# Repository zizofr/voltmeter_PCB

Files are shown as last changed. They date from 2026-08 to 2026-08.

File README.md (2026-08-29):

# ⚡ Digital Voltmeter (Custom PCB & Hardware Design)

A compact digital voltmeter designed around a custom Printed Circuit Board (PCB) created in KiCad. This repository contains the complete hardware design files, schematics, Gerber manufacturing outputs, and board renders prior to final firmware integration.

---

## 🖼️ Hardware & PCB Gallery

### Board Renders & Views
| Top View | Bottom View |
| :---: | :---: |
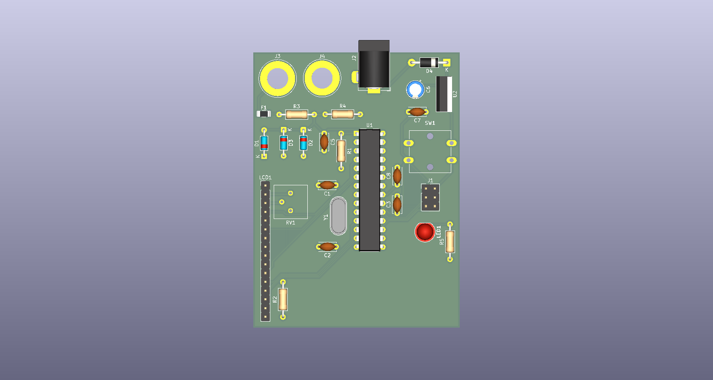
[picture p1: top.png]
Top View
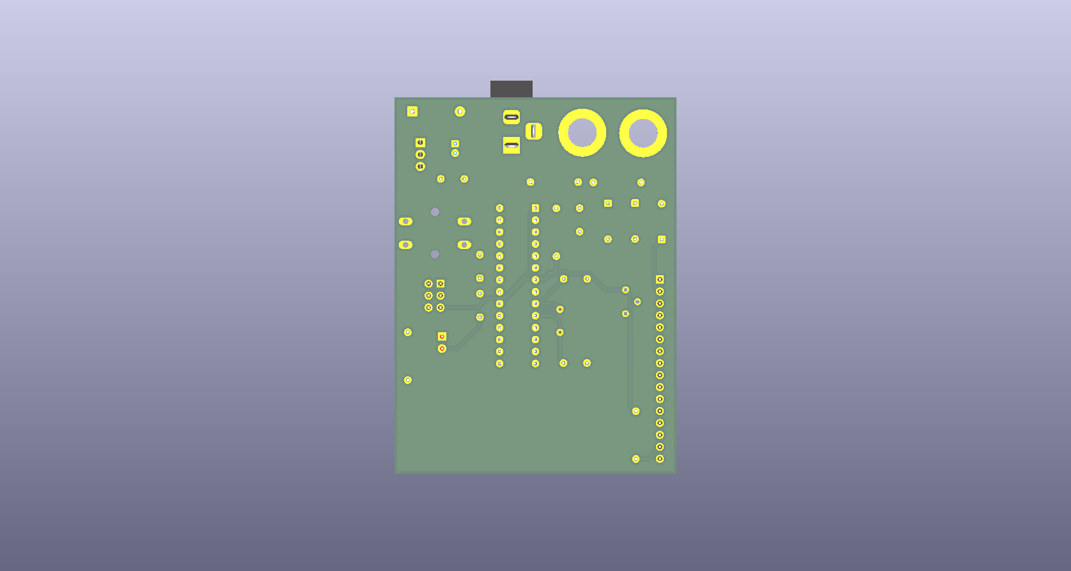
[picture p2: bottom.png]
Bottom View
|  |  |

| Perspective View 1 | Perspective View 2 |
| :---: | :---: |
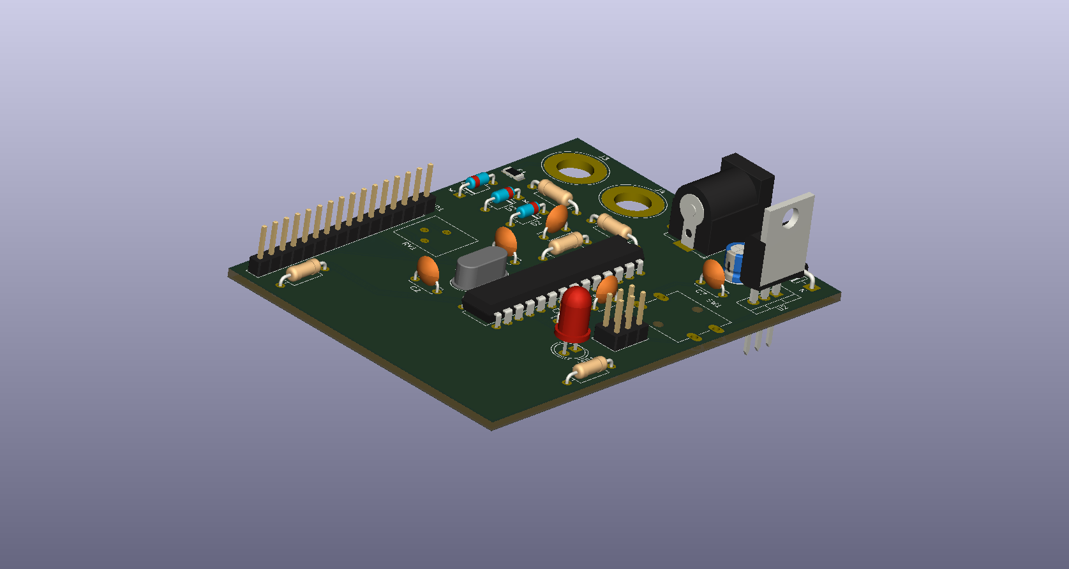
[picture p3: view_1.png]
Perspective View 1
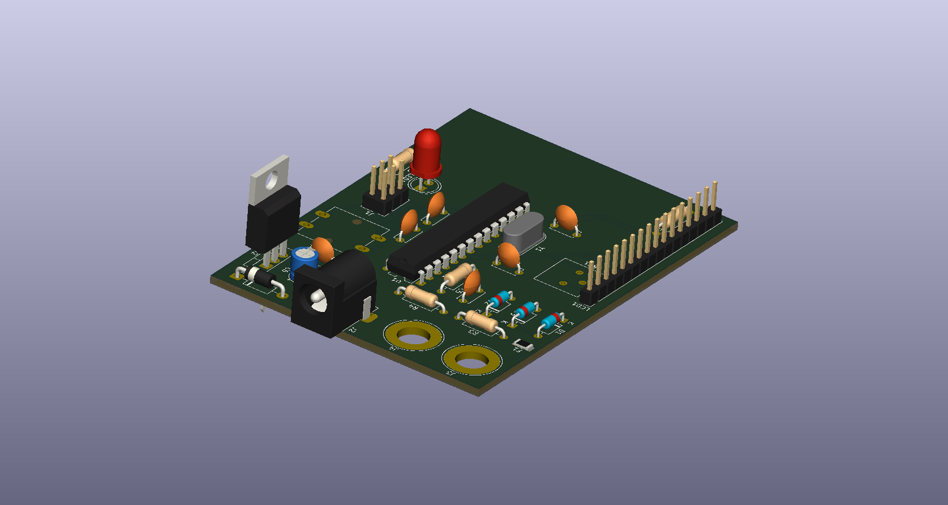
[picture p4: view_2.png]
Perspective View 2
|  |  |

---

## 🛠️ Project Specifications & Features

- **EDA Tool:** KiCad
- **Board Architecture:** Custom 2-layer PCB
- **Hardware Features:**
  - Dedicated analog front-end voltage divider circuit for signal attenuation.
  - Onboard microcontroller interface for ADC sampling and processing.
  - Display interface output.
  - Optimized trace routing with solid ground plane shielding.
- **Manufacturing Package:** Full Gerber layer generation (F_Cu, B_Cu, Solder Masks, Silkscreens, and Drill files).

---

## 📂 Repository Structure

```text
├── gerber/              # Production Gerber and drill files (.gbr, .drl)
├── view_1.png              # High-resolution 3D renders (top, bottom, view_1, view_2)
├──view_2.png
├──top.png
├──bottom.png
├──firmware.ino  # ATmega328P C++ source code
├── voltmeter.kicad_pcb  # KiCad PCB board layout source file
├── voltmeter.kicad_sch  # KiCad schematic design source file
└── README.md            # Project documentation

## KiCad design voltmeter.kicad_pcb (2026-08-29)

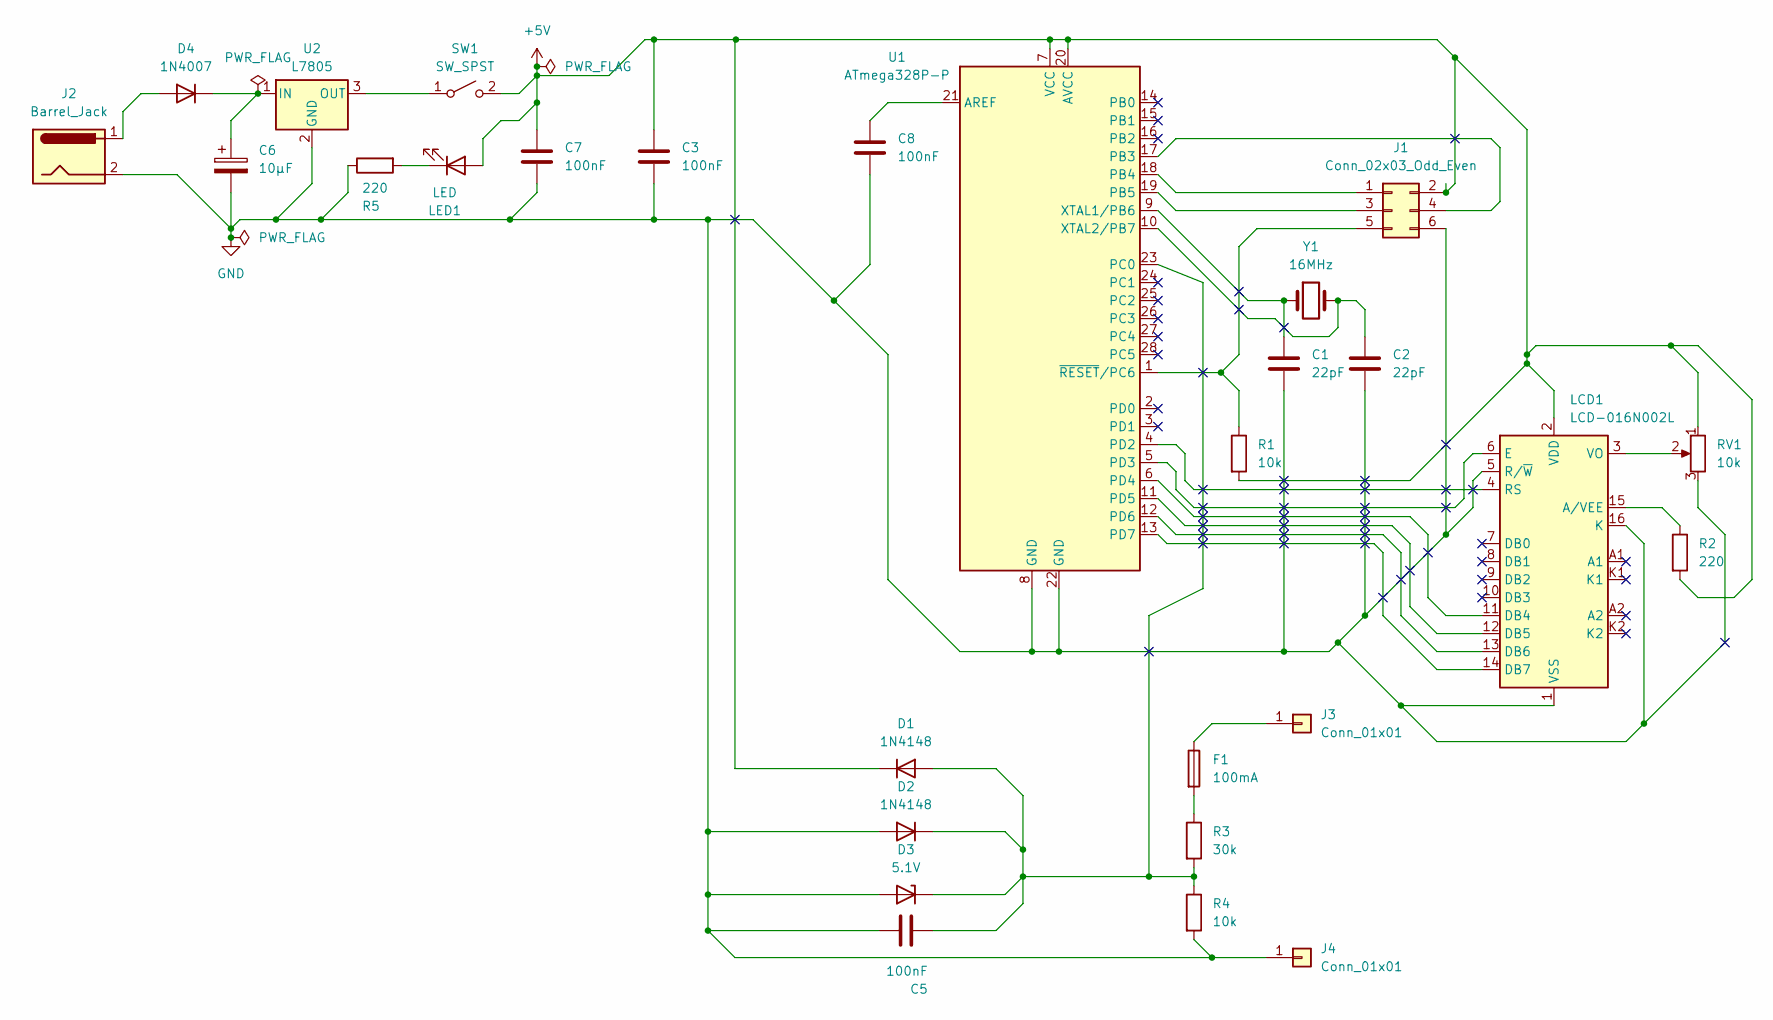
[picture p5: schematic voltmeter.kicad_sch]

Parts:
C1, C2: 22pF; C_Disc_D5.0mm_W2.5mm_P5.00mm
C3, C5, C7, C8: 100nF; C_Disc_D5.0mm_W2.5mm_P5.00mm
C6: 10µF; CP_Radial_D5.0mm_P2.00mm
D1, D2: 1N4148; D_DO-35_SOD27_P7.62mm_Horizontal
D3: 5.1V; D_DO-35_SOD27_P7.62mm_Horizontal
D4: 1N4007; D_DO-41_SOD81_P10.16mm_Horizontal
F1: 100mA; Fuse_1206_3216Metric
J1: Conn_02x03_Odd_Even; PinHeader_2x03_P2.54mm_Vertical
J2: Barrel_Jack; BarrelJack_Horizontal
J3, J4: Conn_01x01; Banana_Jack_1Pin
LCD1: LCD-016N002L; PinHeader_1x16_P2.54mm_Vertical
LED1: LED; LED_D5.0mm
R1, R4: 10k; R_Axial_DIN0207_L6.3mm_D2.5mm_P10.16mm_Horizontal
R2, R5: 220; R_Axial_DIN0207_L6.3mm_D2.5mm_P10.16mm_Horizontal
R3: 30k; R_Axial_DIN0207_L6.3mm_D2.5mm_P10.16mm_Horizontal
RV1: 10k; Potentiometer_Bourns_3386P_Vertical
SW1: SW_SPST; SW_SPST_Omron_B3F-40xx
U1: ATmega328P-P; DIP-28_W7.62mm
U2: L7805; TO-220-3_Vertical
Y1: 16MHz; Crystal_HC49-4H_Vertical

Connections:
+5V: C3.1, C7.1, D1.1 (K), J1.2, LCD1.2 (VDD), LED1.2 (A), R1.2, R2.2, RV1.1, SW1.2 (B), U1.7 (VCC), U1.20 (AVCC)
GND: C1.2, C2.2, C3.2, C5.2, C6.2, C7.2, C8.2, D2.2 (A), D3.2 (A), J1.6, J2.2, J4.1 (Pin_1_1), LCD1.1 (VSS), LCD1.5 (R/~W), LCD1.16 (K), R4.2, R5.1, RV1.3, U1.8 (GND), U1.22 (GND), U2.2 (GND)
unnamed: C5.1, D1.2 (A), D2.1 (K), D3.1 (K), R3.2, R4.1, U1.23 (PC0)
unnamed: D4.2 (A), J2.1
unnamed: C6.1, D4.1 (K), U2.1 (IN)
unnamed: F1.2, R3.1
unnamed: J1.1, U1.18 (PB4)
unnamed: J1.3, U1.19 (PB5)
unnamed: J1.4, U1.17 (PB3)
unnamed: J1.5, R1.1, U1.1 (~RESET/PC6)
unnamed: F1.1, J3.1 (Pin_1_1)
unnamed: LCD1.15 (A/VEE), R2.1
unnamed: LCD1.11 (DB4), U1.6 (PD4)
unnamed: LCD1.12 (DB5), U1.11 (PD5)
unnamed: LCD1.13 (DB6), U1.12 (PD6)
unnamed: LCD1.14 (DB7), U1.13 (PD7)
unnamed: LCD1.6 (E), U1.5 (PD3)
unnamed: LCD1.4 (RS), U1.4 (PD2)
unnamed: LCD1.3 (VO), RV1.2
unnamed: LED1.1 (K), R5.2
unnamed: SW1.1 (A), U2.3 (OUT)
unnamed: C8.1, U1.21 (AREF)
unnamed: C1.1, U1.9 (XTAL1/PB6), Y1.1
unnamed: C2.1, U1.10 (XTAL2/PB7), Y1.2

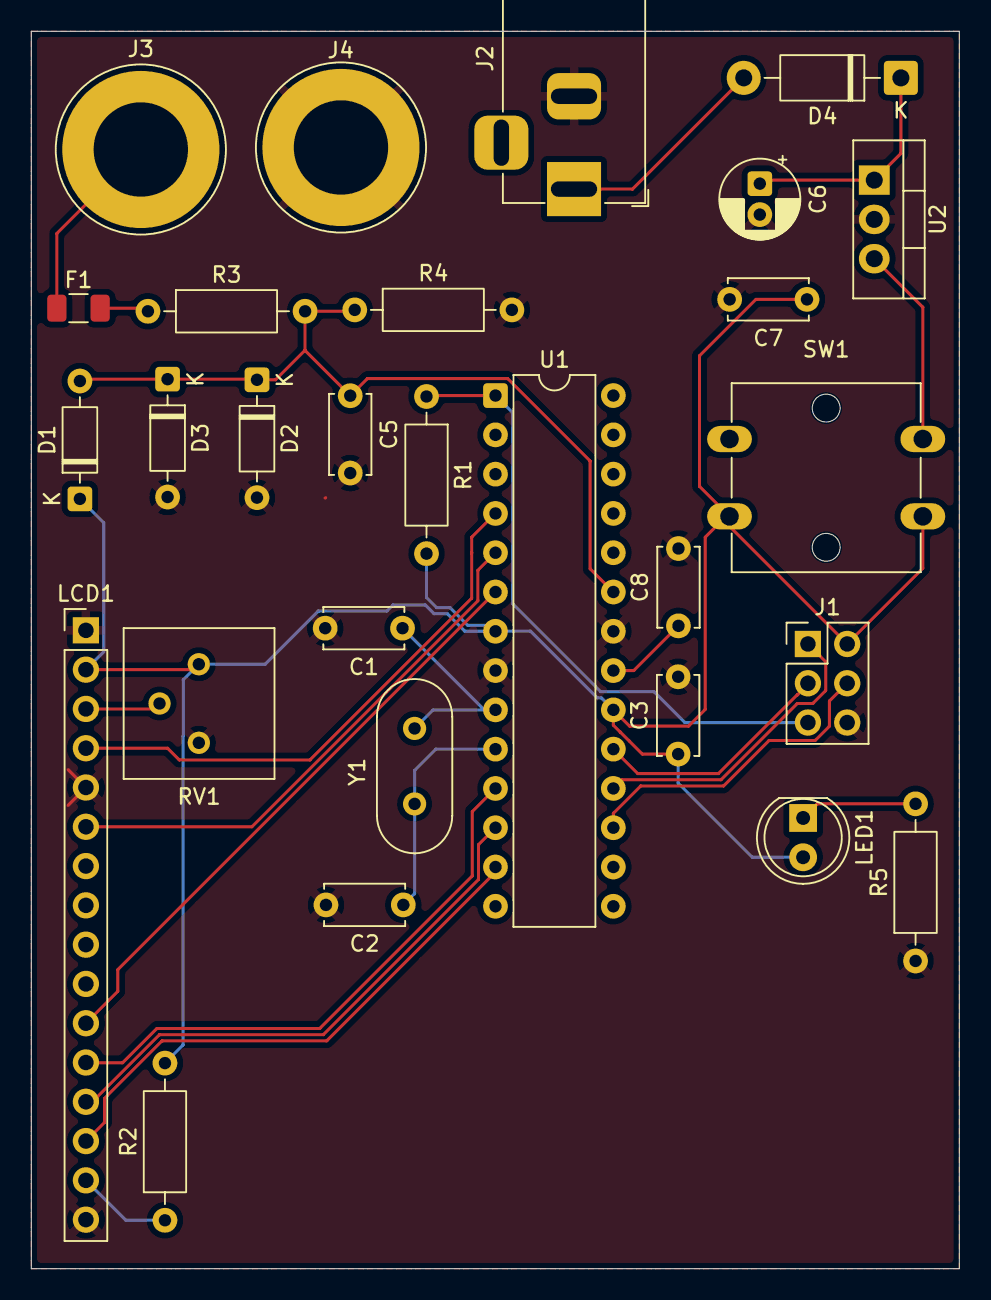
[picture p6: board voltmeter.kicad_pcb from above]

Board: 2 copper layers, 60.0 x 80.0 mm, 28 parts (0 on the bottom side), 24 nets.

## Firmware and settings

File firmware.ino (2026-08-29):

/*
  ============================================
  Digital Voltmeter - Official Firmware v1.0
  ============================================

  Target chip: ATmega328P-P (bare chip, 16MHz external crystal,
  programmed via ISP through J1)

  Function: Reads a 0-20V DC input through a resistor divider
  on ADC0, and displays the measured voltage on a 16x2 LCD.

  --------------------------------------------
  HARDWARE PIN MAPPING (matches the schematic)
  --------------------------------------------
  ATmega pin | Arduino name | Function
  -----------|--------------|------------------
  Pin 4      | D2 (PD2)     | LCD RS
  Pin 5      | D3 (PD3)     | LCD E
  Pin 6      | D4 (PD4)     | LCD DB4
  Pin 11     | D5 (PD5)     | LCD DB5
  Pin 12     | D6 (PD6)     | LCD DB6
  Pin 13     | D7 (PD7)     | LCD DB7
  Pin 23     | A0 (PC0)     | ADC input (from R3/R4 divider)

  --------------------------------------------
  VOLTAGE DIVIDER
  --------------------------------------------
  R3 = 30k (top, from probe input)
  R4 = 10k (bottom, to GND)
  Scales 0-20V input down to 0-5V at the ADC pin.
  Ratio to undo in software = (R3+R4)/R4 = 4.0

  --------------------------------------------
  BEFORE FIRST REAL USE
  --------------------------------------------
  1. Burn the bootloader onto U1 via J1 (if not already done),
     using an Arduino-as-ISP or USBasp programmer, board setting
     "Arduino Uno" (same chip/fuses/16MHz crystal).
  2. Upload this sketch through the same ISP connection.
  3. Calibrate: apply a known, accurate voltage (measured with a
     trusted multimeter) to the probes, and adjust
     CALIBRATION_FACTOR below until the LCD matches that reading.
     Re-upload after changing it.
*/

#include <LiquidCrystal.h>

// ---------------- Pin setup ----------------
const int PIN_RS = 2;
const int PIN_EN = 3;
const int PIN_D4 = 4;
const int PIN_D5 = 5;
const int PIN_D6 = 6;
const int PIN_D7 = 7;

LiquidCrystal lcd(PIN_RS, PIN_EN, PIN_D4, PIN_D5, PIN_D6, PIN_D7);

const int ADC_PIN = A0;

// ---------------- Circuit constants ----------------
const float VREF = 5.0;             // ADC reference voltage (AVCC/AREF)
const int   ADC_MAX = 1023;         // 10-bit ADC resolution
const float DIVIDER_RATIO = 4.0;    // (R3 + R4) / R4 = (30k + 10k) / 10k

// ---------------- Calibration ----------------
// Set this after testing against a known-accurate voltage source.
// Formula: CALIBRATION_FACTOR = actual / displayed
float CALIBRATION_FACTOR = 1.0;

// ---------------- Sampling ----------------
const int   NUM_SAMPLES     = 30;   // averaged per reading, reduces noise/jitter
const int   SAMPLE_DELAY_MS = 2;    // small delay between samples
const int   UPDATE_DELAY_MS = 250;  // how often the display refreshes

// ---------------- Safety display ----------------
const float OVER_RANGE_VOLTS = 20.5; // slightly above rated 20V max

void setup() {
  lcd.begin(16, 2);
  lcd.clear();
  lcd.setCursor(0, 0);
  lcd.print("Digital");
  lcd.setCursor(0, 1);
  lcd.print("Voltmeter v1.0");
  delay(1500);
  lcd.clear();
}

void loop() {
  float vIn = readVoltage();

  lcd.setCursor(0, 0);
  lcd.print("Voltage:");

  lcd.setCursor(0, 1);
  if (vIn > OVER_RANGE_VOLTS) {
    lcd.print("OVER RANGE!   ");
  } else {
    lcd.print(vIn, 2);
    lcd.print(" V");
    lcd.print("      "); // clears leftover digits from a previous longer reading
  }

  delay(UPDATE_DELAY_MS);
}

// Reads and averages the ADC, then converts to the real input voltage
float readVoltage() {
  long sum = 0;
  for (int i = 0; i < NUM_SAMPLES; i++) {
    sum += analogRead(ADC_PIN);
    delay(SAMPLE_DELAY_MS);
  }
  float rawAverage = sum / (float)NUM_SAMPLES;

  float vAtPin = (rawAverage / (float)ADC_MAX) * VREF;
  float vIn = vAtPin * DIVIDER_RATIO * CALIBRATION_FACTOR;

  return vIn;
}
